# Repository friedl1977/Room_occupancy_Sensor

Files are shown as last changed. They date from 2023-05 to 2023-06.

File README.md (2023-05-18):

# ROS

A Particle project named ROS

## Welcome to your project!

Every new Particle project is composed of 3 important elements that you'll see have been created in your project directory for ROS.

#### ```/src``` folder:  
This is the source folder that contains the firmware files for your project. It should *not* be renamed. 
Anything that is in this folder when you compile your project will be sent to our compile service and compiled into a firmware binary for the Particle device that you have targeted.

If your application contains multiple files, they should all be included in the `src` folder. If your firmware depends on Particle libraries, those dependencies are specified in the `project.properties` file referenced below.

#### ```.ino``` file:
This file is the firmware that will run as the primary application on your Particle device. It contains a `setup()` and `loop()` function, and can be written in Wiring or C/C++. For more information about using the Particle firmware API to create firmware for your Particle device, refer to the [Firmware Reference](https://docs.particle.io/reference/firmware/) section of the Particle documentation.

#### ```project.properties``` file:  
This is the file that specifies the name and version number of the libraries that your project depends on. Dependencies are added automatically to your `project.properties` file when you add a library to a project using the `particle library add` command in the CLI or add a library in the Desktop IDE.

## Adding additional files to your project

#### Projects with multiple sources
If you would like add additional files to your application, they should be added to the `/src` folder. All files in the `/src` folder will be sent to the Particle Cloud to produce a compiled binary.

#### Projects with external libraries
If your project includes a library that has not been registered in the Particle libraries system, you should create a new folder named `/lib/<libraryname>/src` under `/<project dir>` and add the `.h`, `.cpp` & `library.properties` files for your library there. Read the [Firmware Libraries guide](https://docs.particle.io/guide/tools-and-features/libraries/) for more details on how to develop libraries. Note that all contents of the `/lib` folder and subfolders will also be sent to the Cloud for compilation.

## Compiling your project

When you're ready to compile your project, make sure you have the correct Particle device target selected and run `particle compile <platform>` in the CLI or click the Compile button in the Desktop IDE. The following files in your project folder will be sent to the compile service:

- Everything in the `/src` folder, including your `.ino` application file
- The `project.properties` file for your project
- Any libraries stored under `lib/<libraryname>/src`

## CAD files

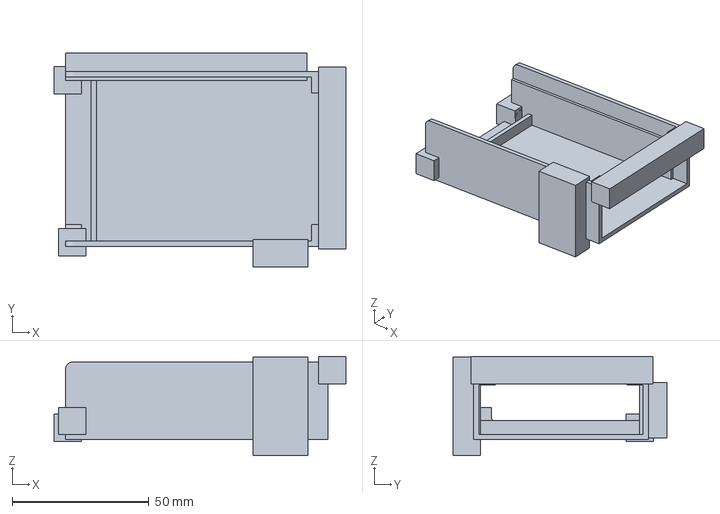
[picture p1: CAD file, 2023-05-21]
STL/ROS_BASE.3mf
106.7 x 78.1 x 36.2 mm

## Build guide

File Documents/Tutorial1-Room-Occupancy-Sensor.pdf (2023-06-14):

# Room Occupancy

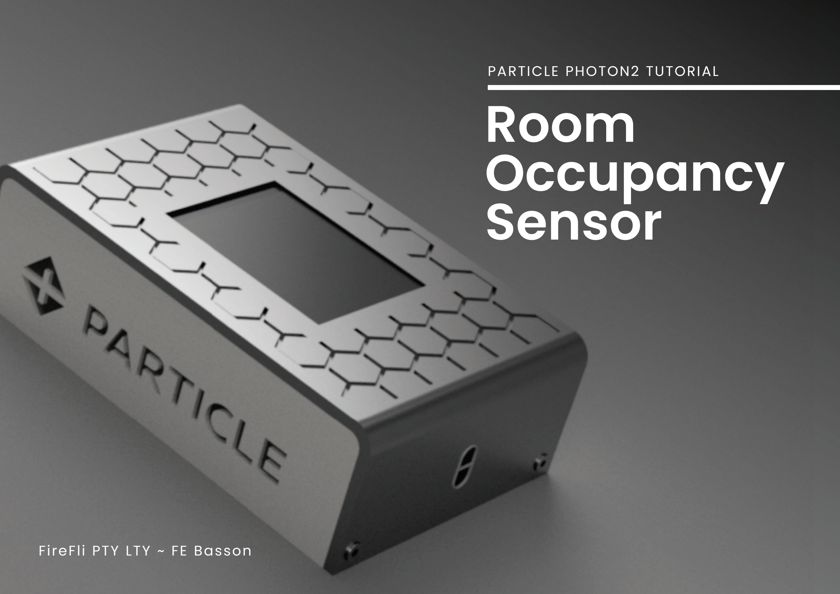
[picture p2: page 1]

# Sensor

# PARTICLE PHOTON2 TUTORIAL

# FireFli PTY LTY ~ FE Basson

# Introduction

The purpose of this project is to construct a battery powered room occupancy sensor from a single ToF sensor from readily available evaluation boards to ensure easy assembly. Of course two sensors could be used which would simplify the code, but installing the second sensor could be diffi-cult as you would have to drill through the door frame for cabling. The single sensor placement ensures easy installation.

The sensor us mounted above the door frame and will count the number of people entering and exiting the room, displaying to total number of people inside the room. In addition to the simplified installation, the sensor automatically calibrates the installation hight, so no need to set this for each application.

We will first construct the BASIC working sensor in case you would prefer publishing the information to Particle Cloud only. We will then add a WAVE 2” TFT display and mount the breadboard, sensor and display inside a 3D printed enclosure for a more complete prototype

# Prerequisites

You should have a basic understanding of Particle WebIDE or Visual Studio Code and how to import libraries.

You should have a Particle Photon2 and a Particle account. If you do not have an account, visit https://www.particle.io and register and account.

You should have at least one Particle Photon2 claimed and active on your account.

# Bill of materials

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
# Items you will need to complete this turorial

Particle Photon2 Breadboard USB cable VL53L1X-SATEL development board 3.7V LiPo battery (or suitable power supply) Jumper Wires (male2-male and male-2-female) 2” WAVE TFT Display 2 x 6mm Machine Screws (optional ~ only for enclosure) 2 x 3.4mm Heat Inserts (optional ~ only for enclosure) 3D printed enclosure (optional ~ STL’s provided)

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
# Software used

### Visual Studio Code

### Cura Slicer

# Step 1

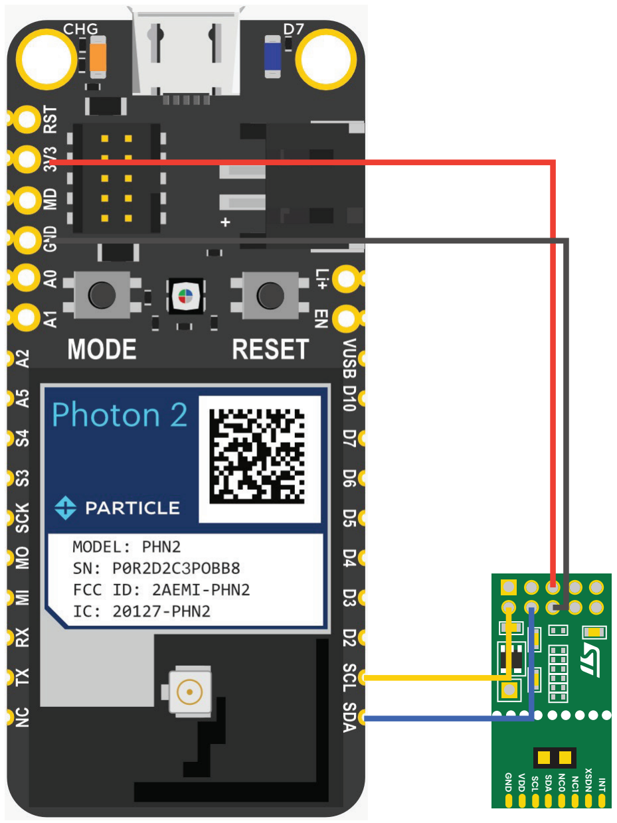
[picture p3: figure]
INT; XSDN; GND VDD SCL; SDA

# Connecting the ToF Sensor

Place your Particle Photon2 on the breadboard and ensure there are exposed holes on either side as we will be connecting wired on both sides of the Photon2.

Make the necessary connections between die Photon2 and the VL53L1X-SATEL

## Photon 2

3V3
GND
SDA
SCL

## VL53L1

VIN
GND
SDA
SCL

NOTE
The VL53L1X sensor does have optional INT and XSHUT pins but they can be left NC for the purpose of this tutorial.

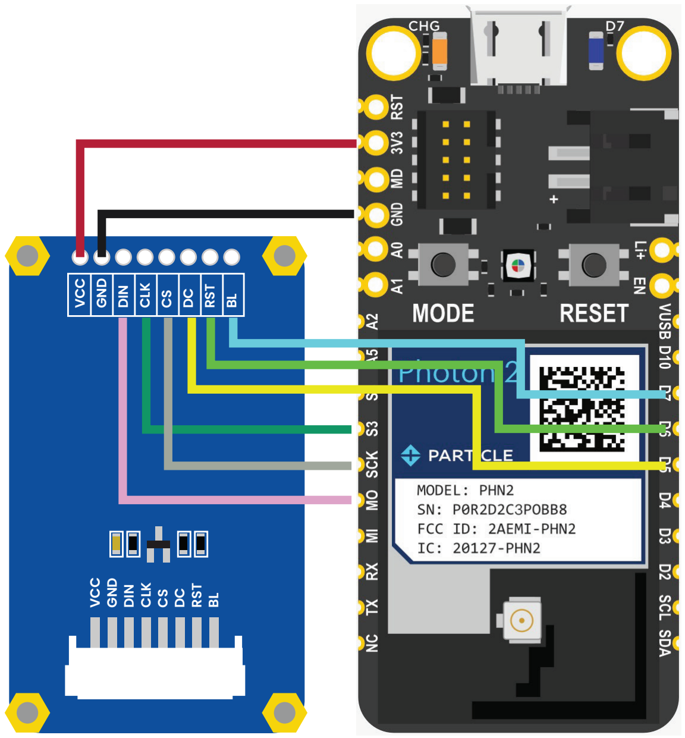
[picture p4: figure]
VCC GND DIN; CLK CS; RST BL

# Step 2

# Connecting the ToF Sensor

This part can be a little more involved so pay careful attention to the wiring.

## Photon 2

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
## WAVE 2”

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
NOTE
You can use either the connector and wire harness that came with the screen, or solder headers onto board depending on you connection preference

# Step 3

Recap Place your Particle Photon2 on the breadboard and ensure there are exposed holes on either side as we will be connecting wired on both sides of the Photon2.

Make the necessary connections between die Photon2 and the VL53L1X-SATEL

NOTE
:Depending on the jumper wires you selected, it might look a little different but as long as the pin outs match all should be good.

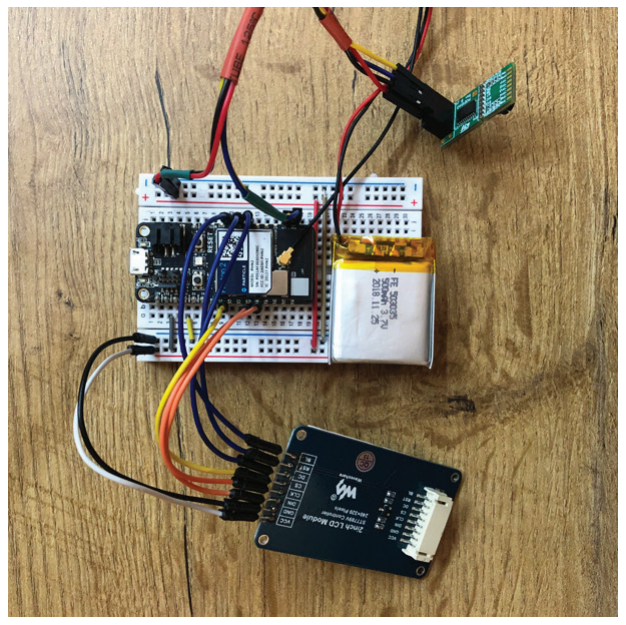
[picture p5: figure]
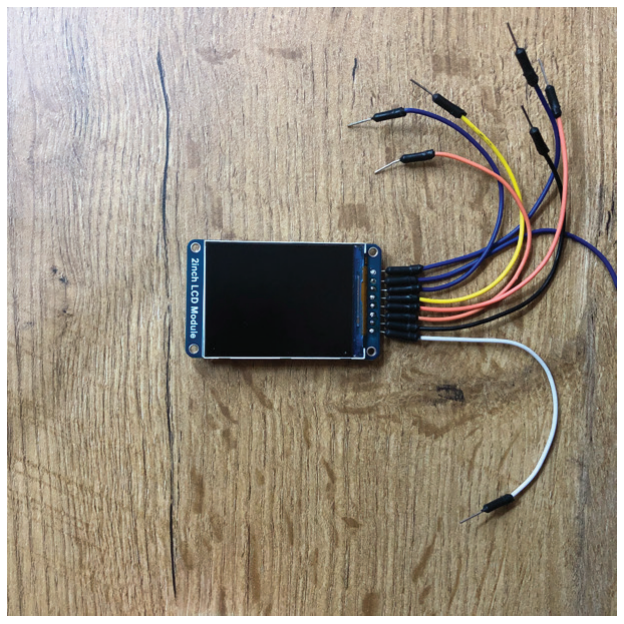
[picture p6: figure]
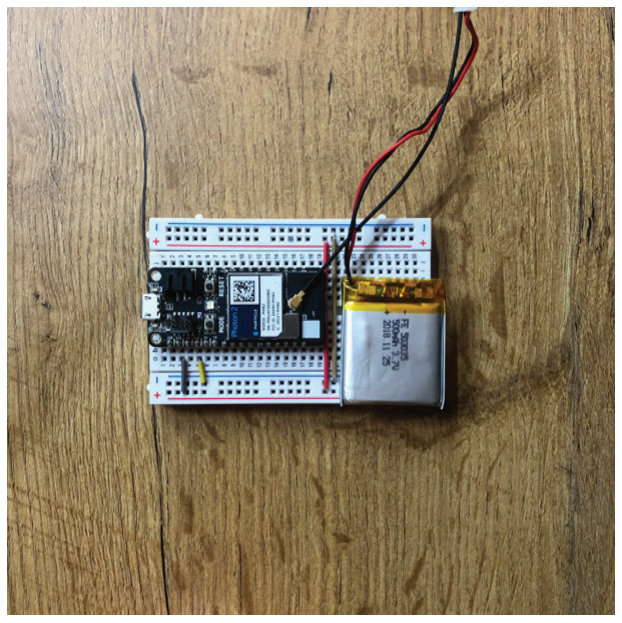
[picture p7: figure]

Step 1 | Step 2 | Step 3

# Step 4

# Installing

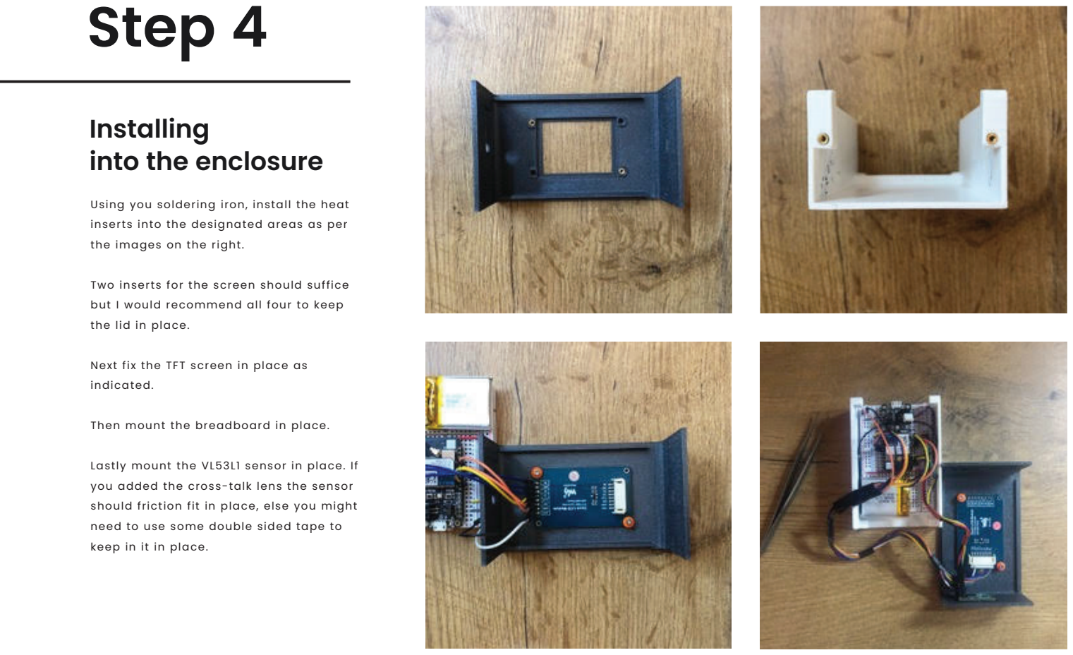
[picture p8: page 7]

# into the enclosure

Using you soldering iron, install the heat inserts into the designated areas as per the images on the right.

Two inserts for the screen should suffice but I would recommend all four to keep the lid in place.

Next fix the TFT screen in place as indicated.

Then mount the breadboard in place.

Lastly mount the VL53L1 sensor in place. If you added the cross-talk lens the sensor should friction fit in place, else you might need to use some double sided tape to keep in it in place.

Code Everything has been done for you. Simply follow the link below and download the entire project from the Github repository.

## https://github.com/friedl1977/ROS

The repository also includes a folder with STL and STEP files if you want to print the enclosure or need to make some modifications on the design.

The code is quite heavily commented for informational purposes. You are welcome to remove these, but please keep all mentions of contributors in place if you intend to publish this code as some parts are loosely based on existing libraries even though quite heavily amended.

NOTE
If you are using Visual Studio Code, make sure to use a USB cable to flash. If you use cloud flash, the libraries hosted on the sever will be used and your display will not function as intended.

The library in this project has been amended to accommodate the 2” display

# Step 5

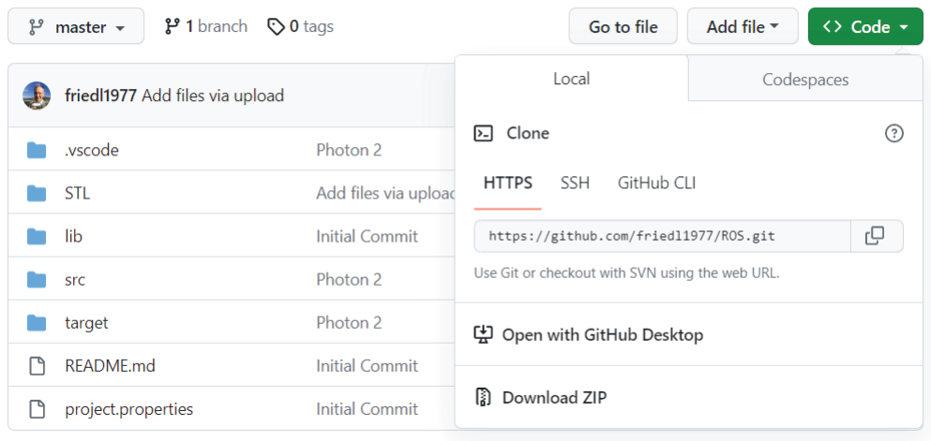
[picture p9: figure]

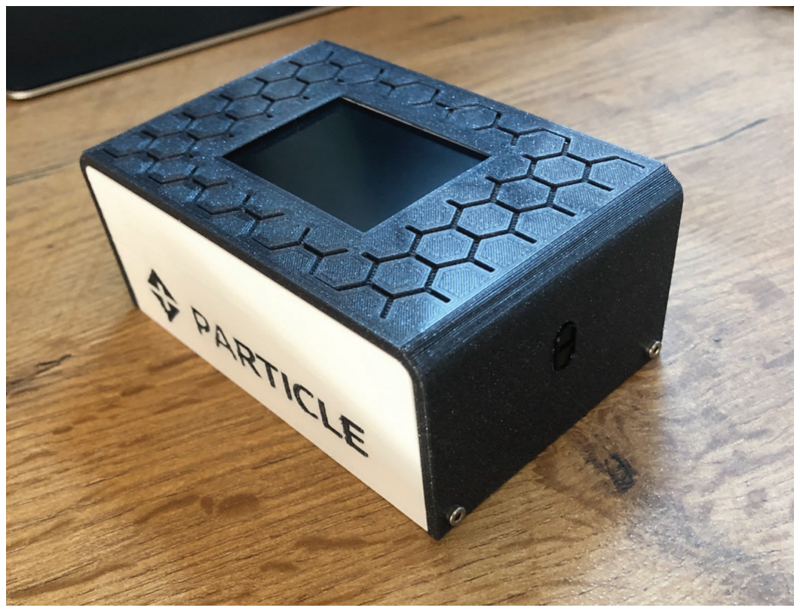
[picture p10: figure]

# Step 6

# Working principal

The sensor is intended to be mounted above the door frame.

During setup, the sensor runs the calibration function which determines the distance between the sensor and the floor. It is crucial that the sensor be in place at the time of the calibration process.

When ready the sensor will display “0” in the screen. As people passes under it, the sensor will determine the direction the person is travelling in and either add/subtract.

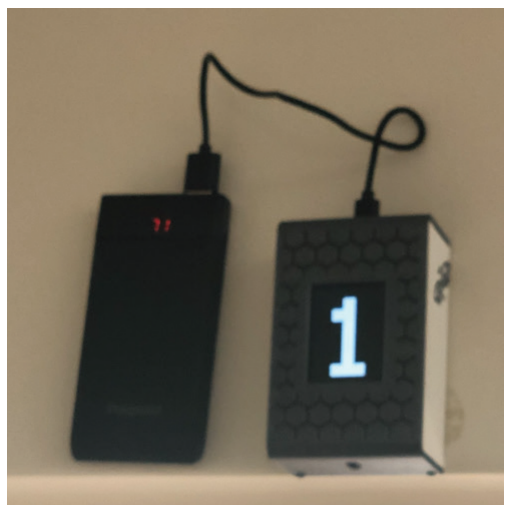
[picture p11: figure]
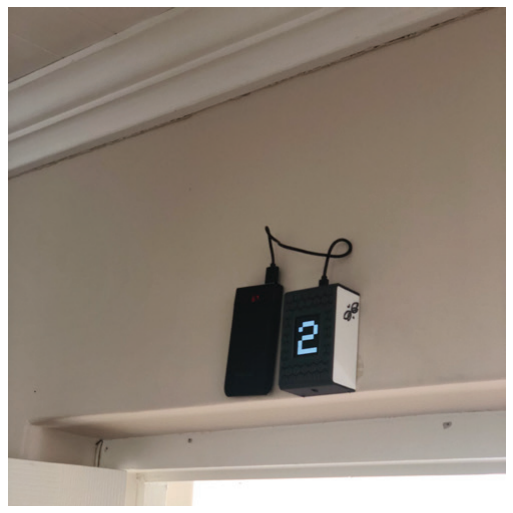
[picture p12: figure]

The sensor displays the total number of people current in the room.

To ZERO the sensor, simply hold you hand (or something) within 100mm from the sensor until it resets to “0”

# Room for imporovement

Add a power switch (simple ON/OFF) in case you want to use an internal battery

Refine the code - A LOT. There is definitely room for improvement on the algorithm that determines the direction of the person travelling.

The VL53L1X sensor has it’s limitations in terms of reading speed. Increasing the scan speed to much will reduce the accuracy and cause false readings.

Two sensors would be more accurate in my opinion, but installation would be more challenging as you would need to install on sensor each side of the door. The there is no physical door, this would be easy enough.

If you intend to use this product , DESIGN A PCB instead of using a breadboard. While breadboards are acceptable means for rapid prototyping, the present many challenges.

# Enjoy the project!!

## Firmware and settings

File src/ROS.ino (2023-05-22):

// Include VL53L1x ToF libraries // 
#include "vl53l1x_class.h"
#include "SparkFun_VL53L1X.h"

// VL53L1x ToF definitions // 
#define SHUTDOWN_PIN 2          // OPTIONAL Shut Down pin    
#define INTERRUPT_PIN 3         // OPTIONAL Interrupt pin

SFEVL53L1X distanceSensor(Wire);

float calibrated_zone_0;
float calibrated_zone_1;

int sum_zone_0 = 0;
int sum_zone_1 = 0;

int average_zone_0;
int average_zone_1;

int zone_state = 0;
uint16_t distance = 0;

int number_attempts;
int PathTrack[3][2];

int counter = 0;

static int DIST_THRESHOLD_MAX = 0.75;
//static int MIN_DISTANCE[] = {0, 0};

static int center[2] = {0,0};   // center of the two zones 
static int Zone = 0;

int ROI_height = 0;
int ROI_width = 0;

int ROUTE[3] = {0,0,0};
int Entry_state;
int Exit_state;


// Include ST7789 TFT Display libraries //
#include "../lib/Adafruit_GFX_RK/src/Adafruit_GFX.h"
#include "../lib/Adafruit_ST7735_RK/src/Adafruit_ST7789.h"
#include <SPI.h>

// ST7789 TFT  definitions // 
#define TFT_CS        S3
#define TFT_RST       D6        
#define TFT_DC        D5

Adafruit_ST7789 tft = Adafruit_ST7789(TFT_CS, TFT_DC, TFT_RST);     // Hardware SPI

float p = 3.1415926;

void setup(void) {

  // TFT Setup //
  Serial.begin(9600);
  tft.init(240, 320);                                               // Init ST7789 320x240

  uint16_t time = millis();
  tft.fillScreen(ST77XX_BLACK);
  time = millis() - time;

  // ToF Setup //
  Wire.begin();
  zones_calibration();

  if (distanceSensor.init() == false)
    Particle.publish("Counter is online");
    delay(2000);
    Particle.publish("I am ready", PRIVATE);

    tft.setTextWrap(false);
    tft.fillScreen(ST77XX_BLACK);
    tft.setCursor(30, 30);
    tft.setTextColor(ST77XX_WHITE);
    tft.setTextSize(36);
    tft.print("0");
    delay(50);
}

void zones_calibration() {

  center[0] = 231; //167
  center[1] = 167; //231 
  
  ROI_height = 8;
  ROI_width = 8;
  
  delay(500);
  Zone = 0;
  
  sum_zone_0 = 0;
  sum_zone_1 = 0;
  
  distance = 0;
  
  number_attempts = 20;
  
  for (int i=0; i<number_attempts; i++){
      
      // Zone 0
      distanceSensor.setIntermeasurementPeriod(55);
      distanceSensor.setDistanceModeLong();
      distanceSensor.setROI(ROI_height, ROI_width, center[0]);  // first value: height of the zone, second value: width of the zone
      delay(50);
      distanceSensor.setTimingBudgetInMs(50);
      distanceSensor.startRanging();                            //Write configuration bytes to initiate measurement
      distance = distanceSensor.getDistance();                  //Get the result of the measurement from the sensor
      distanceSensor.stopRanging();      
      sum_zone_0 = sum_zone_0 + distance;
      Zone++;
      Zone = Zone%2;

      // Zone 1
      distanceSensor.setIntermeasurementPeriod(55);
      distanceSensor.setDistanceModeLong();
      distanceSensor.setROI(ROI_height, ROI_width, center[1]);  // first value: height of the zone, second value: width of the zone
      delay(50);
      distanceSensor.setTimingBudgetInMs(50);
      distanceSensor.startRanging();                            //Write configuration bytes to initiate measurement
      distance = distanceSensor.getDistance();                  //Get the result of the measurement from the sensor
      distanceSensor.stopRanging();      
      sum_zone_1 = sum_zone_1 + distance;
      Zone++;
      Zone = Zone%2;
      
  }
  
  // after we have computed the sum for each zone, we can compute the average distance of each zone
  calibrated_zone_0 = sum_zone_0 / number_attempts;
  calibrated_zone_1 = sum_zone_1 / number_attempts;
  
  //DIST_THRESHOLD_MAX = (((calibrated_zone_0 + calibrated_zone_1)/2) * (threshold)); 
  
  Particle.publish("Zones_C: ", String(calibrated_zone_0) + " & " + String(calibrated_zone_1), PRIVATE);

}

void measure_zones() {
 
    distance = 0;
    sum_zone_0 = 0;
    sum_zone_1 = 0;
    number_attempts = 1;
    
    Zone = 0;

  // MONITORING ZONES  //

    for (int i=0; i<number_attempts; i++) {
    
    // increase sum of values in Zone 
      distanceSensor.setIntermeasurementPeriod(35);
      distanceSensor.setDistanceModeLong();
      distanceSensor.setROI(ROI_height, ROI_width, center[0]);  // first value: height of the zone, second value: width of the zone
      delay(25);
      distanceSensor.setTimingBudgetInMs(33);
      distanceSensor.startRanging();                            //Write configuration bytes to initiate measurement
      distance = distanceSensor.getDistance();                  //Get the result of the measurement from the sensor
      distanceSensor.stopRanging();      
      sum_zone_0 = sum_zone_0 + distance;
      Zone++;
      Zone = Zone%2;

      // increase sum of values in Zone 1
      distanceSensor.setIntermeasurementPeriod(35);
      distanceSensor.setDistanceModeLong();
      distanceSensor.setROI(ROI_height, ROI_width, center[1]);  // first value: height of the zone, second value: width of the zone
      delay(25);
      distanceSensor.setTimingBudgetInMs(33);
      distanceSensor.startRanging();                            //Write configuration bytes to initiate measurement
      distance = distanceSensor.getDistance();                  //Get the result of the measurement from the sensor
      distanceSensor.stopRanging();      
      sum_zone_1 = sum_zone_1 + distance;
      Zone++;
      Zone = Zone%2;
    }
    
        
// IF SOMEONE IS DETECTED -- CALL PATHTRACK //
   
    if ((sum_zone_0 <= (calibrated_zone_0 * 0.75)) || (sum_zone_1 <= (calibrated_zone_1 * 0.75))) {
        delay(10);
        Path();
        } else {
               }
}
    
void Path() {
    
    distance = 0;
    number_attempts = 2;
    
    Zone = 0;
    
    //START PATHTRACK //
    
    // measure 3 times //if ((ROUTE[0] == 1) && 
    for (int k=0; k<3; k++) {  
        
            sum_zone_0 = 0;
            sum_zone_1 = 0;
        
        for (int i=0; i<number_attempts; i++) {

    // increase sum of values in Zone 0 //
            distanceSensor.setIntermeasurementPeriod(35);
            distanceSensor.setDistanceModeLong();
            distanceSensor.setROI(ROI_height, ROI_width, center[0]);    // first value: height of the zone, second value: width of the zone
            delay(30);
            distanceSensor.setTimingBudgetInMs(33);
            distanceSensor.startRanging();                              //Write configuration bytes to initiate measurement
            distance = distanceSensor.getDistance();                    //Get the result of the measurement from the sensor
            distanceSensor.stopRanging();      
            sum_zone_0 = sum_zone_0 + distance;
            Zone++;
            Zone = Zone%2;
            
            delay(10);

    // increase sum of values in Zone 1 //
            distanceSensor.setIntermeasurementPeriod(35);
            distanceSensor.setDistanceModeLong();
            distanceSensor.setROI(ROI_height, ROI_width, center[1]);    // first value: height of the zone, second value: width of the zone
            delay(30);
            distanceSensor.setTimingBudgetInMs(33);
            distanceSensor.startRanging();                              //Write configuration bytes to initiate measurement
            distance = distanceSensor.getDistance();                    //Get the result of the measurement from the sensor
            distanceSensor.stopRanging();      
            sum_zone_1 = sum_zone_1 + distance;
            Zone++;
            Zone = Zone%2;
    
            PathTrack[k][0] = sum_zone_0 / number_attempts;
            PathTrack[k][1] = sum_zone_1 / number_attempts;

            if (sum_zone_0 < 20) { 
            counter = 0;
            tft.setTextWrap(false);
            tft.fillScreen(ST77XX_BLACK);
            tft.setCursor(30, 30);
            tft.setTextColor(ST77XX_WHITE);
            tft.setTextSize(36);
            tft.print(counter);
            //delay(1500);
            delay(1500);
            }
        }
    
       // Particle.publish("Zone 1: " + String(PathTrack[k][0]) + " &  Zone 2:" + String(PathTrack[k][1]), PRIVATE);  // DEBUG
        }
     
      people_counter_array();   
}    
  
void people_counter_array() {

    // PROCESS ENTRY // 

    if (PathTrack[0][0] < PathTrack[0][1]) {
        ROUTE[0] = 1;
    } else {
        ROUTE[0] = 2;
    }
    
    if (PathTrack[1][0] > PathTrack[1][1]) {
        ROUTE[1] = 1;
    } else {
        ROUTE[1] = 2;
        }
    
    if ((PathTrack[2][0] > PathTrack[1][0]) &&  (PathTrack[2][1] > PathTrack[1][1])) {
        ROUTE[2] = 1;
    } else {
        ROUTE[2] = 2;
    } 
    
    if ((ROUTE[0] == 1) && (ROUTE[1] == 1) && (ROUTE[2] == 1))  {
        Particle.publish("Entry ", PRIVATE);
        Entry_state = 1;
        Exit_state = 0;

    } else if ((ROUTE[0] == 2) && (ROUTE[1] == 2) && (ROUTE[2] == 1)) {
        Particle.publish("Exit ", PRIVATE);
        Entry_state = 0;
        Exit_state = 1;
    }
    
   // Particle.publish("Route : " + String(ROUTE[0]) + String(ROUTE[1]) + String(ROUTE[2]), PRIVATE);     // DEBUG

    ROUTE[0] = 0;
    ROUTE[1] = 0;
    ROUTE[2] = 0;
    
    count();
  
}

void count() {
    
    if ((Entry_state == 1) && (Exit_state == 0)) { 
        counter = counter + 1;
        Particle.publish("Counter: " + String(counter), PRIVATE);
        TFT();
        Entry_state = 0;
    }
    
    if ((Entry_state == 0) && (Exit_state == 1)) { 
        counter = counter - 1;    
        Particle.publish("Counter: " + String(counter), PRIVATE);
        TFT();
        Exit_state = 0;
    }    

    if (counter <= 0) {
        counter = 0;
    }
    
}


void loop() {

  measure_zones();

}

  void TFT() {
  tft.setTextWrap(false);
  tft.fillScreen(ST77XX_BLACK);
  tft.setCursor(30, 30);
  tft.setTextColor(ST77XX_WHITE);
  tft.setTextSize(36);
  tft.print(counter);
  //delay(1500);
  delay(1500);
}
